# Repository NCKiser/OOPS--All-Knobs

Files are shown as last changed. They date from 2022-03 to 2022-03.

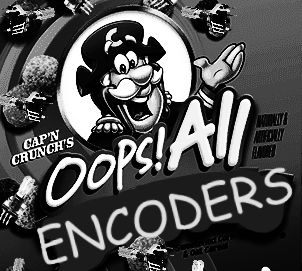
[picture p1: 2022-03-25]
imageedit_3_2700160076.png

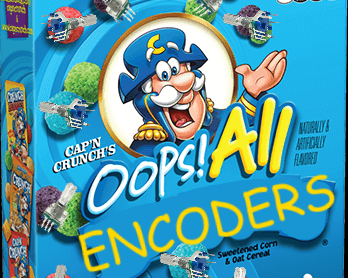
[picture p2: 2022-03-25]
PCBart.png

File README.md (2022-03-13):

# OOPS! All Encoders
A 19mm (Planck) spaced 4x12 PCB that has the option for an encoder in every switch position.
Runs on an rp2040. Should fit in most Planck cases low-, mid-, or high-profile.
There is currently no license for this work. Do not distribute or monetize without approval from Noah Kiser.

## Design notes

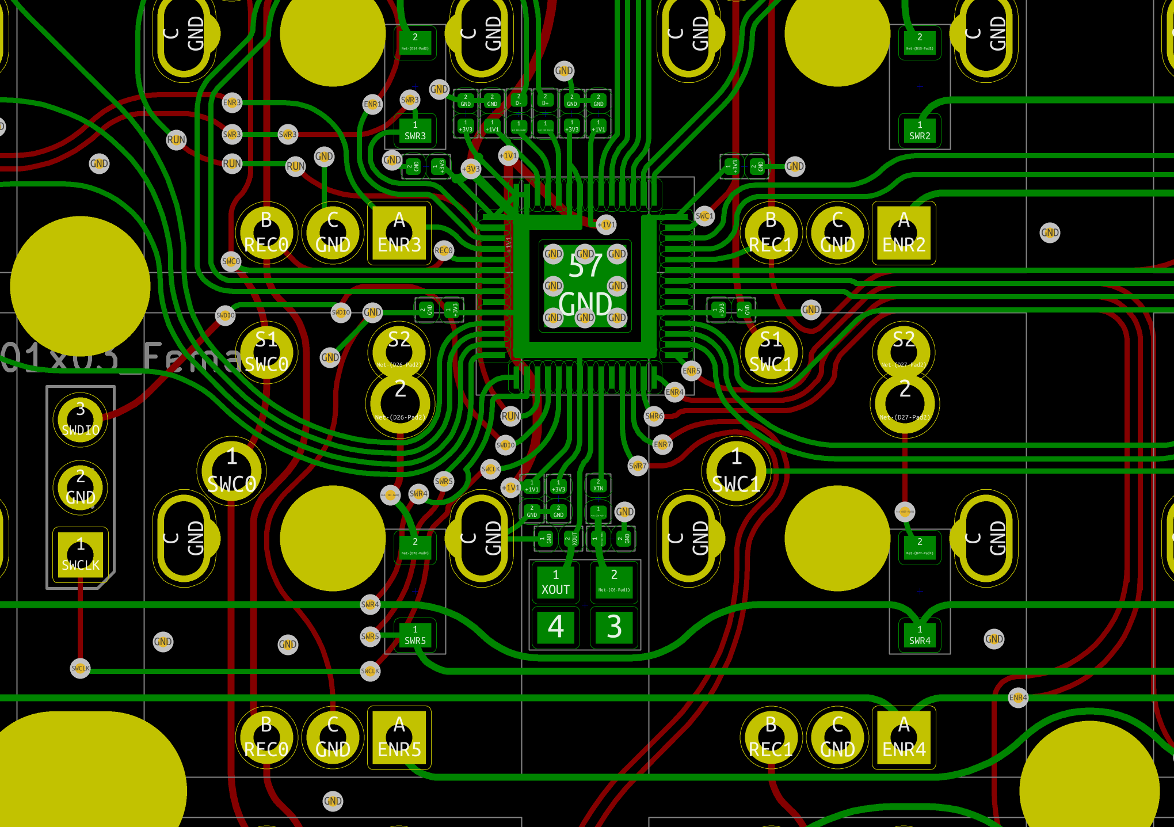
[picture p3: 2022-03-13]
Controller.png

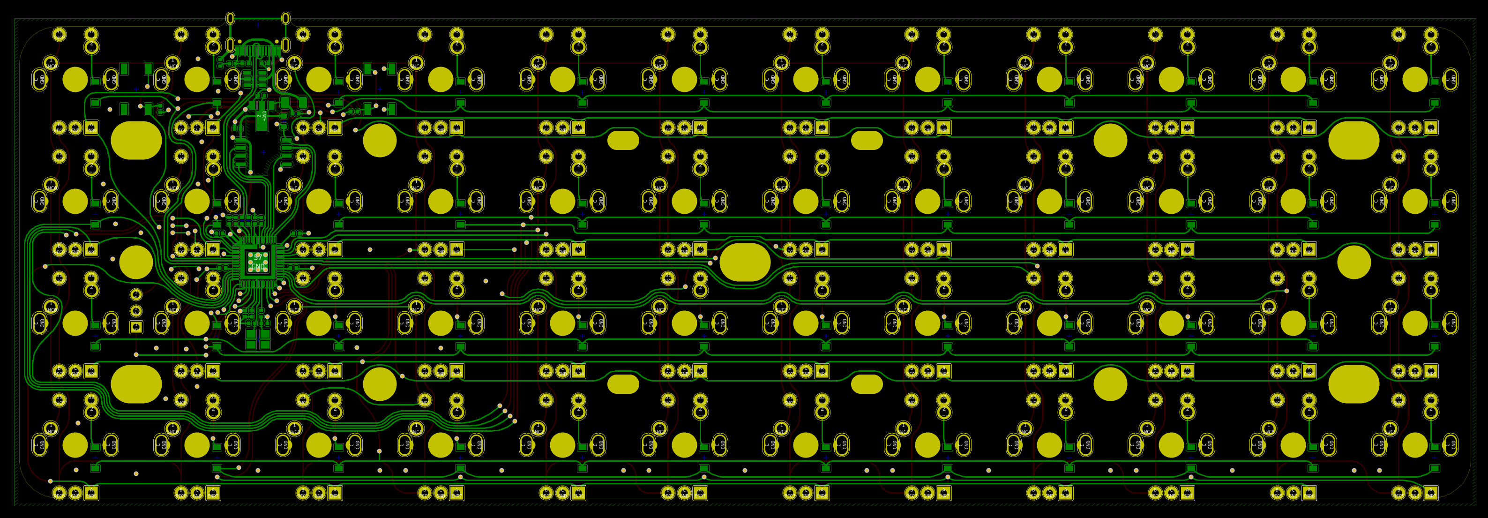
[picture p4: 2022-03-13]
PCB_Back.png

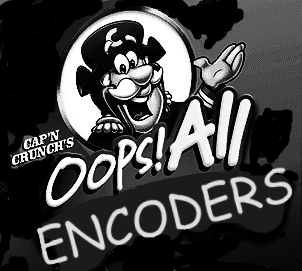
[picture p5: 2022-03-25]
imageedit_3_7217835309.png

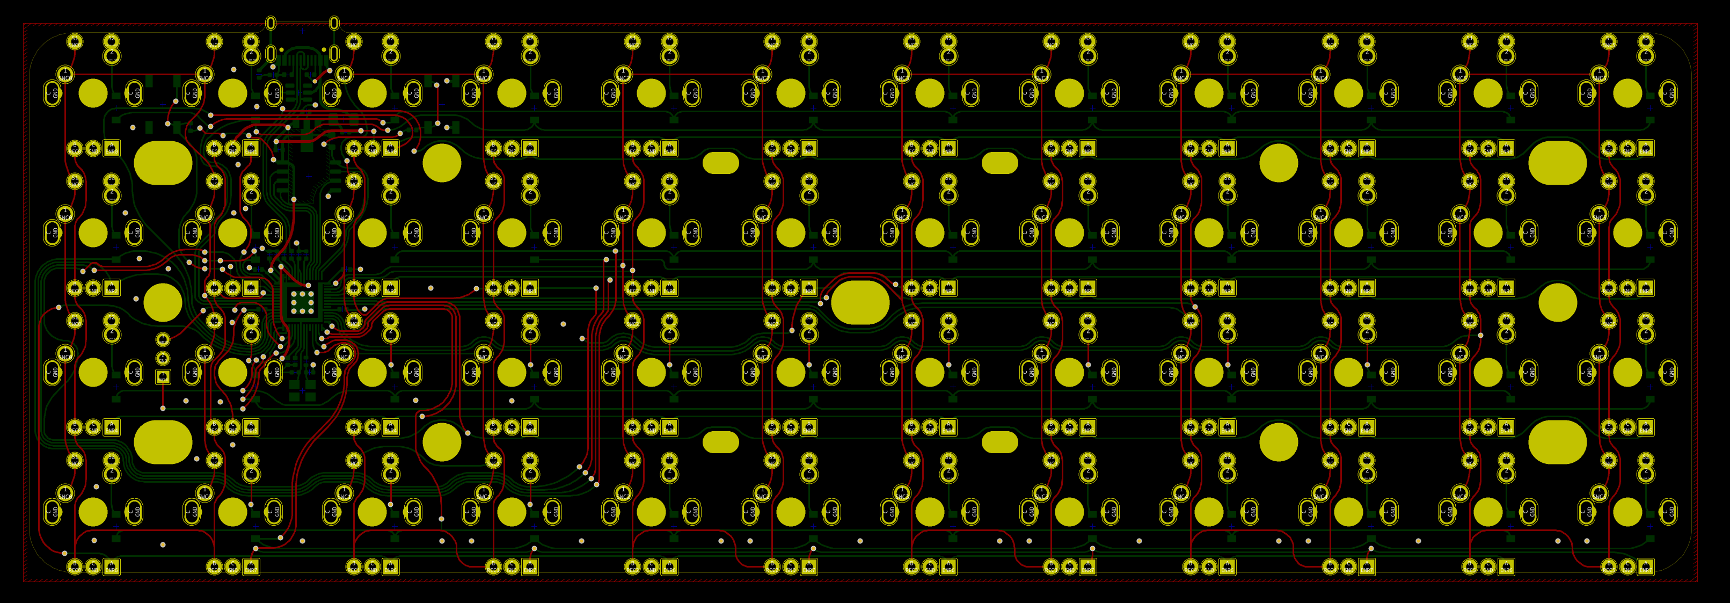
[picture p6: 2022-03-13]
PCB_Front.png

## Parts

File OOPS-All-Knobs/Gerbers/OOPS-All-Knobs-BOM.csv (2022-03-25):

Comment | Designator | Footprint | LCSC Part Number | Quantity
D_Small | D44,D9,D28,D4,D1,D23,D45,D43,D38,D16,D11,D26,D13,D39,D5,D19,D22,D36,D27,D21,D14,D37,D30,D35,D10,D12,D18,D34,D3,D48,D31,D42,D32,D25,D24,D41,D40,D8,D47,D33,D20,D29,D2,D15,D17,D6,D7,D46 | D_SOD-123 | C81598 | 48
100n | C10,C14,C4,C8,C12,C11,C13,C9,C7 | C_0402_1005Metric | C307331 | 9
1M | R3 | R_0402_1005Metric | C26083 | 1
1k | R8,R5 | R_0402_1005Metric | C11702 | 2
30p | C6,C5 | C_0402_1005Metric | C1570 | 2
XC6206-3.3_SOT23 | U1 | SOT-23 | C5446 | 1
SW_SPST | SW1,SW2 | SW_SPST_TL3342 | C318884 | 2
500mA | F1 | Fuse_1206_3216Metric | C70076 | 1
12MHz | Y1 | Crystal_SMD_3225-4Pin_3.2x2.5mm | C9002 | 1
22 | R6,R7 | R_0402_1005Metric | C25092 | 2
W25Q128JVS | U2 | SOIC-8_5.23x5.23mm_P1.27mm | C97521 | 1
USB_C_Receptacle_USB2.0 | J1 | USB_C_Receptacle_HRO_TYPE-C-31-M-12 | C165948 | 1
5.1k | R2,R9,R1 | R_0402_1005Metric | C25905 | 3
10u | C1,C2,C15 | C_0402_1005Metric | C15525 | 3
1u | C18,C17 | C_0402_1005Metric | C52923 | 2
SRV05-4 | U4 | SOT-23-6-routable | C85364 | 1
-10k | R4 | R_0603_1608Metric |  | 1
RP2040TR7 | U3 | QFN40P700X700X90-57N | C2040 | 1
4.7n | C3 | C_0402_1005Metric | C1538 | 1

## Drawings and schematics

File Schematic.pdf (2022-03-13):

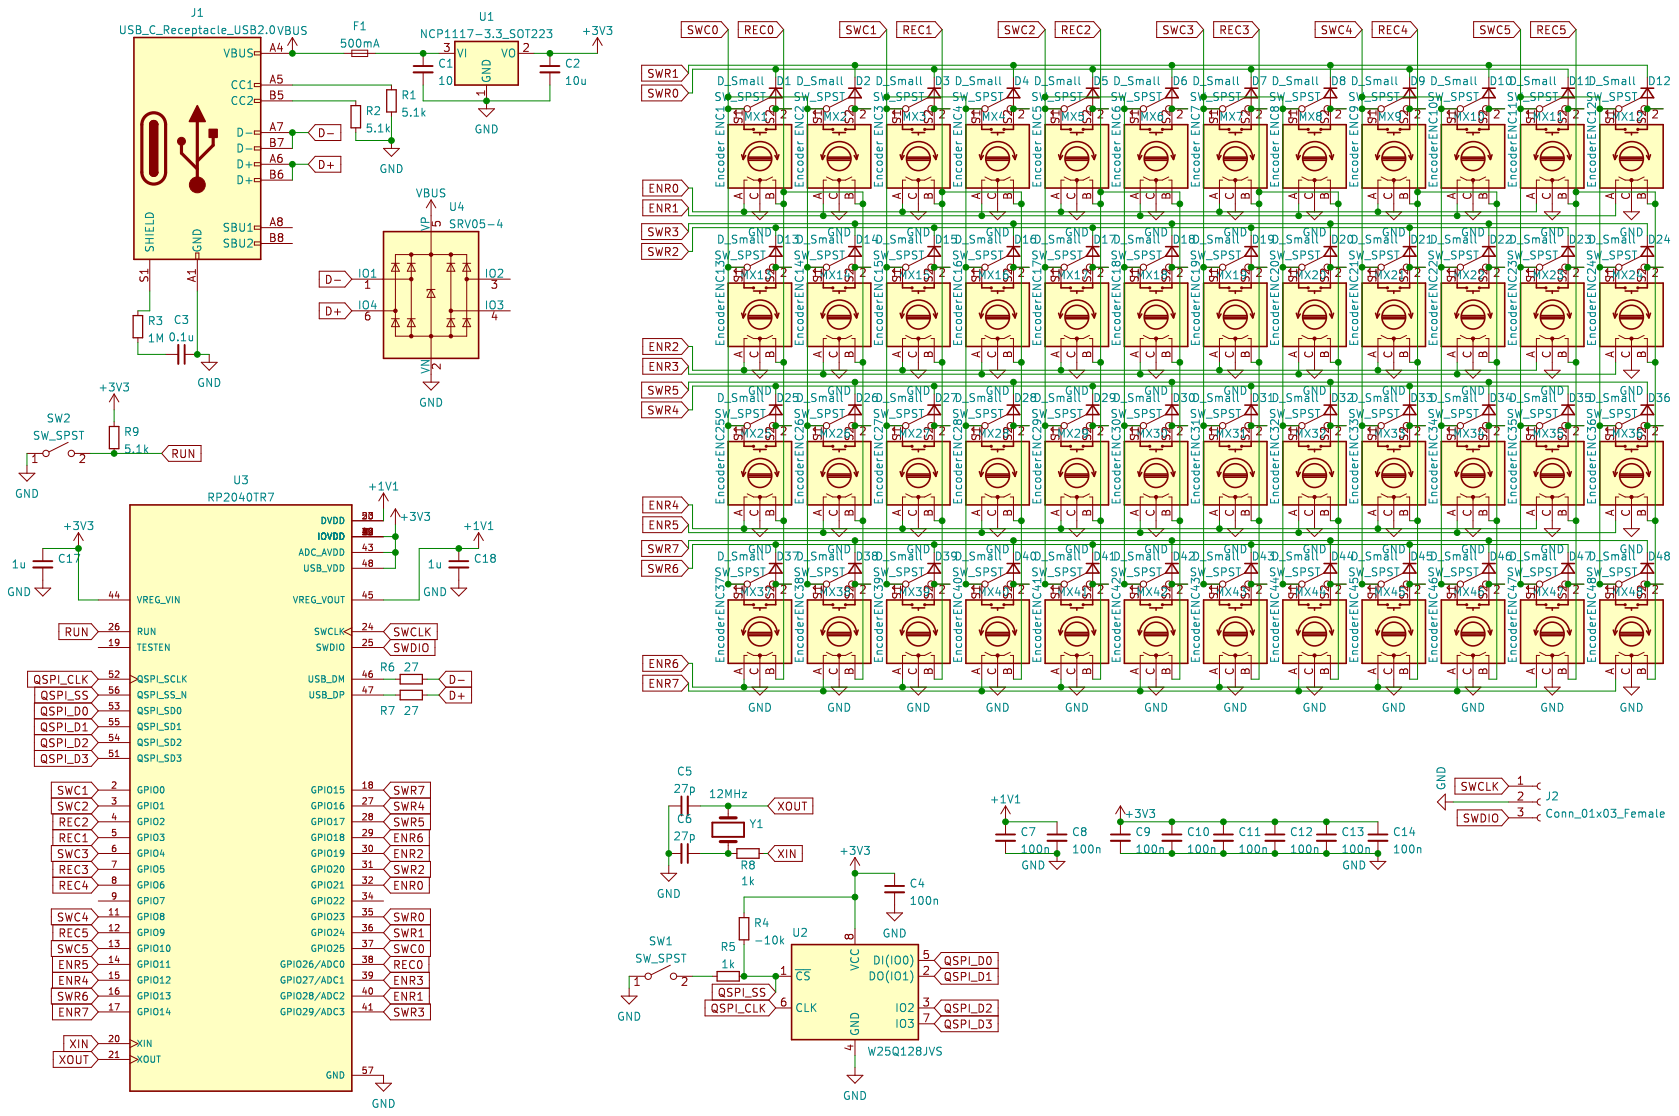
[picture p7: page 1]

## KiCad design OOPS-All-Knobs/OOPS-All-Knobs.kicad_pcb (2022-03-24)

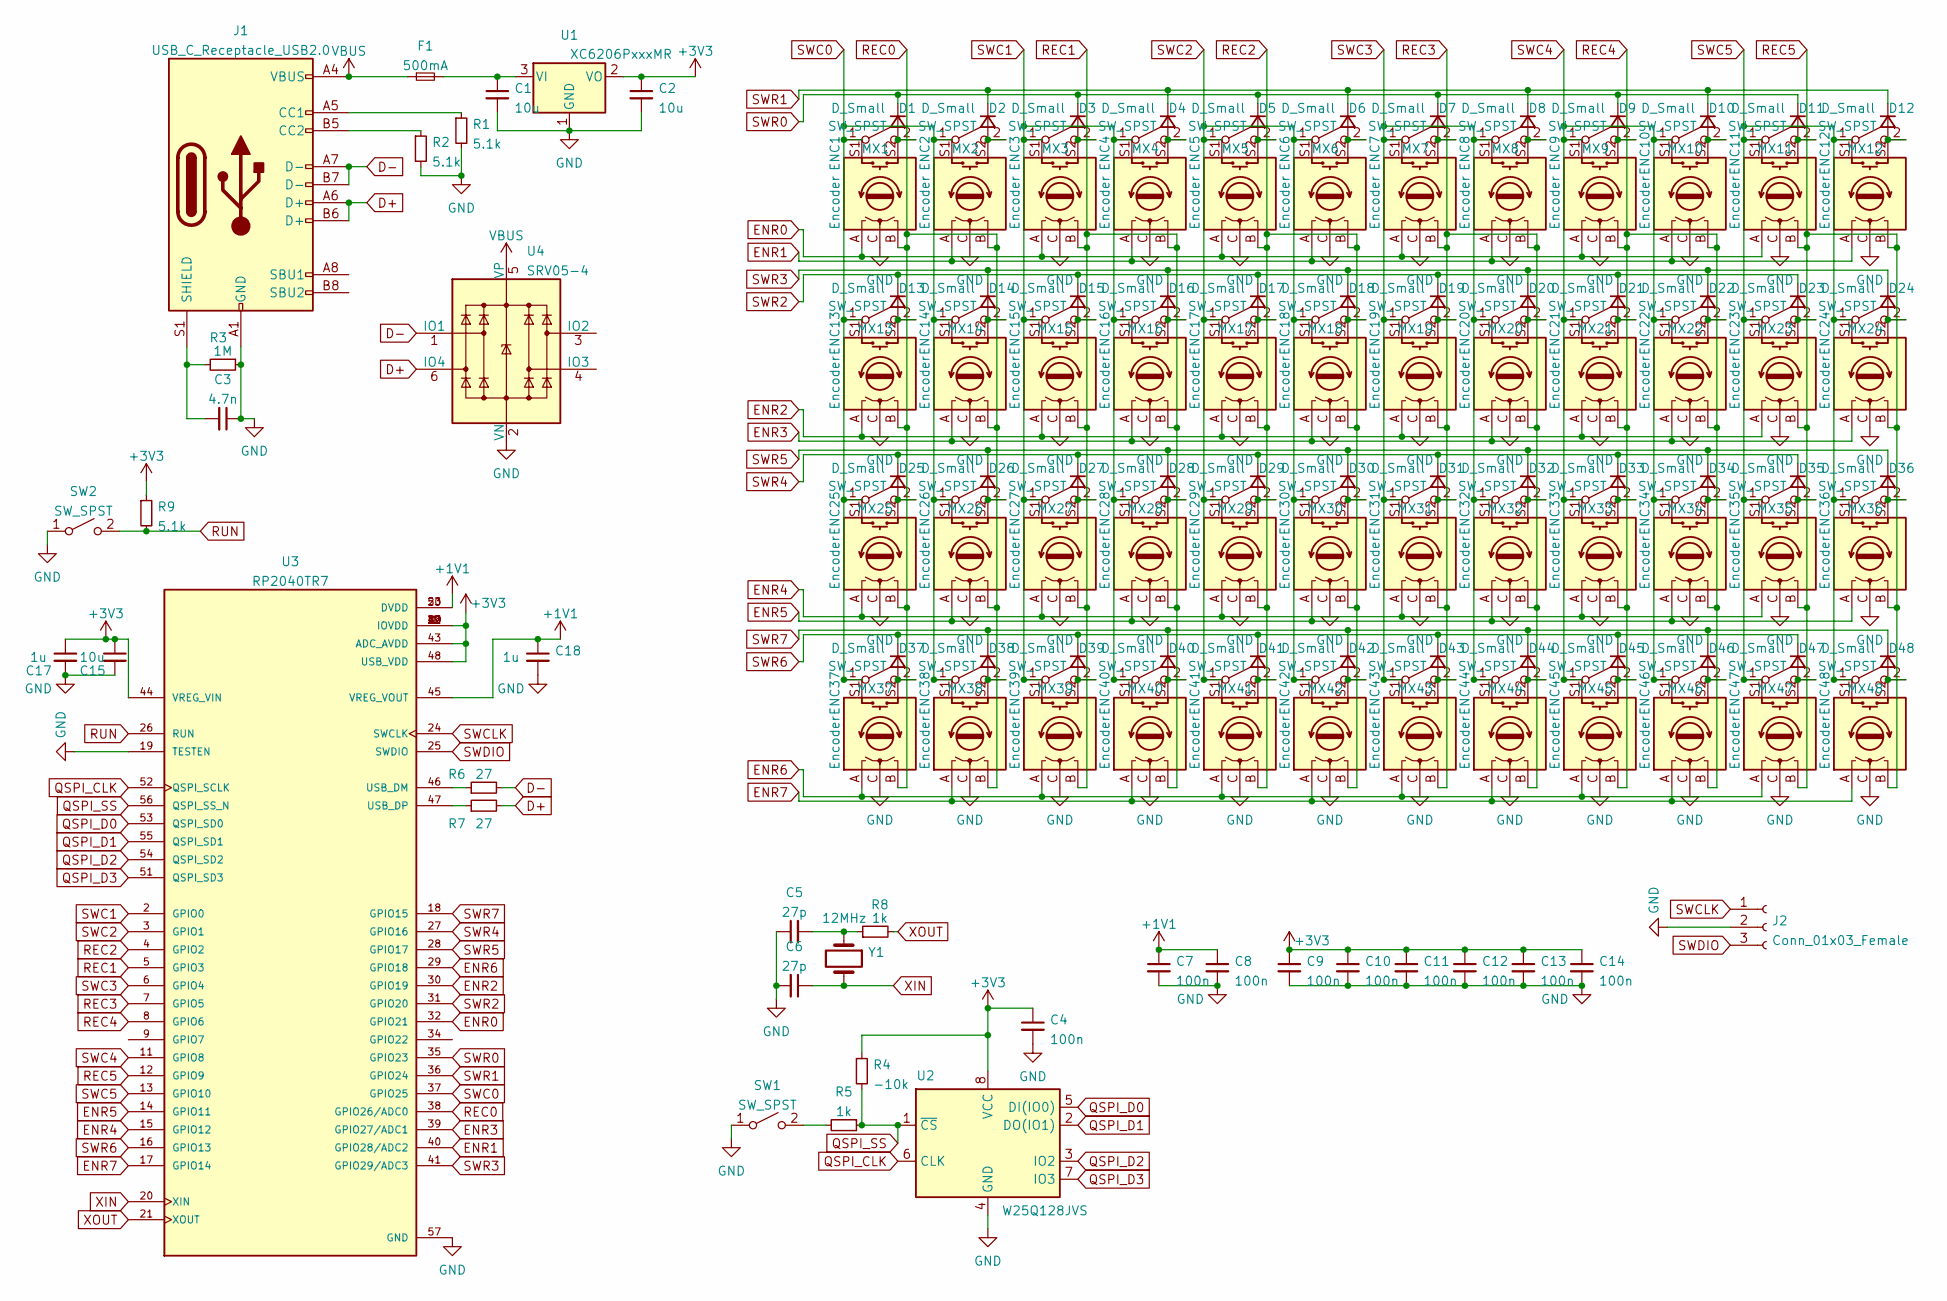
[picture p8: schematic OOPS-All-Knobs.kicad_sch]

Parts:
C1, C2, C15: 10u; C_0402_1005Metric
C3: 4.7n; C_0402_1005Metric
C4, C7, C8, C9, C10, C11, C12, C13, C14: 100n; C_0402_1005Metric
C5, C6: 27p; C_0402_1005Metric
C17, C18: 1u; C_0402_1005Metric
D1, D2, D3, D4, D5, D6, D7, D8, D9, D10, D11, D12, D13, D14, D15, D16, D17, D18, D19, D20, D21, D22, D23, D24, D25, D26, D27, D28, D29, D30, D31, D32, D33, D34, D35, D36, D37, D38, D39, D40, D41, D42, D43, D44, D45, D46, D47, D48: D_Small; D_SOD-123
ENC1, ENC2, ENC3, ENC4, ENC5, ENC6, ENC7, ENC8, ENC9, ENC10, ENC11, ENC12, ENC13, ENC14, ENC15, ENC16, ENC17, ENC18, ENC19, ENC20, ENC21, ENC22, ENC23, ENC24, ENC25, ENC26, ENC27, ENC28, ENC29, ENC30, ENC31, ENC32, ENC33, ENC34, ENC35, ENC36, ENC37, ENC38, ENC39, ENC40, ENC41, ENC42, ENC43, ENC44, ENC45, ENC46, ENC47, ENC48: Encoder; RotaryEncoder_Alps_EC11E-Switch_Vertical_H20mm
F1: 500mA; Fuse_1206_3216Metric
J1: USB_C_Receptacle_USB2.0; USB_C_Receptacle_HRO_TYPE-C-31-M-12
J2: Conn_01x03_Female; PinHeader_1x03_P2.54mm_Vertical
MX1, MX2, MX3, MX4, MX5, MX6, MX7, MX8, MX9, MX10, MX11, MX12, MX13, MX14, MX15, MX16, MX17, MX18, MX19, MX20, MX21, MX22, MX23, MX24, MX25, MX26, MX27, MX28, MX29, MX30, MX31, MX32, MX33, MX34, MX35, MX36, MX37, MX38, MX39, MX40, MX41, MX42, MX43, MX44, MX45, MX46, MX47, MX48: SW_SPST; MXOnly-1U-NoLED
R1, R2, R9: 5.1k; R_0402_1005Metric
R3: 1M; R_0402_1005Metric
R4: -10k; R_0603_1608Metric
R5, R8: 1k; R_0402_1005Metric
R6, R7: 27; R_0402_1005Metric
SW1, SW2: SW_SPST; SW_SPST_TL3342
U1: XC6206PxxxMR; SOT-23
U2: W25Q128JVS; SOIC-8_5.23x5.23mm_P1.27mm
U3: RP2040TR7; QFN40P700X700X90-57N; PARTREV 1.7.1
U4: SRV05-4; SOT-23-6-routable
Y1: 12MHz; Crystal_SMD_3225-4Pin_3.2x2.5mm

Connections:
+1V1: C7.1, C8.1, C18.1, U3.23 (DVDD), U3.45 (VREG_VOUT), U3.50 (DVDD)
+3V3: C2.1, C4.1, C9.1, C10.1, C11.1, C12.1, C13.1, C14.1, C15.1, C17.1, R4.1, R9.1, U1.2 (VO), U2.8 (VCC), U3.1 (IOVDD), U3.10 (IOVDD), U3.22 (IOVDD), U3.33 (IOVDD), U3.42 (IOVDD), U3.43 (ADC_AVDD), U3.44 (VREG_VIN), U3.48 (USB_VDD), U3.49 (IOVDD)
D+: J1.A6 (D+), J1.B6 (D+), R7.2, U4.6 (IO4)
D-: J1.A7 (D-), J1.B7 (D-), R6.2, U4.1 (IO1)
ENR0: ENC1.A, ENC3.A, ENC5.A, ENC7.A, ENC9.A, ENC11.A, U3.32 (GPIO21)
ENR1: ENC2.A, ENC4.A, ENC6.A, ENC8.A, ENC10.A, ENC12.A, U3.40 (GPIO28/ADC2)
ENR2: ENC13.A, ENC15.A, ENC17.A, ENC19.A, ENC21.A, ENC23.A, U3.30 (GPIO19)
ENR3: ENC14.A, ENC16.A, ENC18.A, ENC20.A, ENC22.A, ENC24.A, U3.39 (GPIO27/ADC1)
ENR4: ENC25.A, ENC27.A, ENC29.A, ENC31.A, ENC33.A, ENC35.A, U3.15 (GPIO12)
ENR5: ENC26.A, ENC28.A, ENC30.A, ENC32.A, ENC34.A, ENC36.A, U3.14 (GPIO11)
ENR6: ENC37.A, ENC39.A, ENC41.A, ENC43.A, ENC45.A, ENC47.A, U3.29 (GPIO18)
ENR7: ENC38.A, ENC40.A, ENC42.A, ENC44.A, ENC46.A, ENC48.A, U3.17 (GPIO14)
GND: C1.2, C2.2, C3.1, C4.2, C5.1, C6.2, C7.2, C8.2, C9.2, C10.2, C11.2, C12.2, C13.2, C14.2, C15.2, C17.2, C18.2, ENC1.C, ENC2.C, ENC3.C, ENC4.C, ENC5.C, ENC6.C, ENC7.C, ENC8.C, ENC9.C, ENC10.C, ENC11.C, ENC12.C, ENC13.C, ENC14.C, ENC15.C, ENC16.C, ENC17.C, ENC18.C, ENC19.C, ENC20.C, ENC21.C, ENC22.C, ENC23.C, ENC24.C, ENC25.C, ENC26.C, ENC27.C, ENC28.C, ENC29.C, ENC30.C, ENC31.C, ENC32.C, ENC33.C, ENC34.C, ENC35.C, ENC36.C, ENC37.C, ENC38.C, ENC39.C, ENC40.C, ENC41.C, ENC42.C, ENC43.C, ENC44.C, ENC45.C, ENC46.C, ENC47.C, ENC48.C, J1.A1 (GND), J1.A12 (GND), J1.B1 (GND), J1.B12 (GND), J2.2, R1.2, R2.2, R3.1, SW1.1 (A), SW2.1 (A), U1.1 (GND), U2.4 (GND), U3.19 (TESTEN), U3.57 (GND), U4.2 (VN)
unnamed: C1.1, F1.2, U1.3 (VI)
unnamed: C3.2, J1.S1 (SHIELD), R3.2
unnamed: C5.2, R8.1, Y1.1
unnamed: D1.2 (A), ENC1.S2, MX1.2 (B)
unnamed: D2.2 (A), ENC2.S2, MX2.2 (B)
unnamed: D3.2 (A), ENC3.S2, MX3.2 (B)
unnamed: D4.2 (A), ENC4.S2, MX4.2 (B)
unnamed: D5.2 (A), ENC5.S2, MX5.2 (B)
unnamed: D6.2 (A), ENC6.S2, MX6.2 (B)
unnamed: D7.2 (A), ENC7.S2, MX7.2 (B)
unnamed: D8.2 (A), ENC8.S2, MX8.2 (B)
unnamed: D9.2 (A), ENC9.S2, MX9.2 (B)
unnamed: D10.2 (A), ENC10.S2, MX10.2 (B)
unnamed: D11.2 (A), ENC11.S2, MX11.2 (B)
unnamed: D12.2 (A), ENC12.S2, MX12.2 (B)
unnamed: D13.2 (A), ENC13.S2, MX13.2 (B)
unnamed: D14.2 (A), ENC14.S2, MX14.2 (B)
unnamed: D15.2 (A), ENC15.S2, MX15.2 (B)
unnamed: D16.2 (A), ENC16.S2, MX16.2 (B)
unnamed: D17.2 (A), ENC17.S2, MX17.2 (B)
unnamed: D18.2 (A), ENC18.S2, MX18.2 (B)
unnamed: D19.2 (A), ENC19.S2, MX19.2 (B)
unnamed: D20.2 (A), ENC20.S2, MX20.2 (B)
unnamed: D21.2 (A), ENC21.S2, MX21.2 (B)
unnamed: D22.2 (A), ENC22.S2, MX22.2 (B)
unnamed: D23.2 (A), ENC23.S2, MX23.2 (B)
unnamed: D24.2 (A), ENC24.S2, MX24.2 (B)
unnamed: D25.2 (A), ENC25.S2, MX25.2 (B)
unnamed: D26.2 (A), ENC26.S2, MX26.2 (B)
unnamed: D27.2 (A), ENC27.S2, MX27.2 (B)
unnamed: D28.2 (A), ENC28.S2, MX28.2 (B)
unnamed: D29.2 (A), ENC29.S2, MX29.2 (B)
unnamed: D30.2 (A), ENC30.S2, MX30.2 (B)
unnamed: D31.2 (A), ENC31.S2, MX31.2 (B)
unnamed: D32.2 (A), ENC32.S2, MX32.2 (B)
unnamed: D33.2 (A), ENC33.S2, MX33.2 (B)
unnamed: D34.2 (A), ENC34.S2, MX34.2 (B)
unnamed: D35.2 (A), ENC35.S2, MX35.2 (B)
unnamed: D36.2 (A), ENC36.S2, MX36.2 (B)
unnamed: D37.2 (A), ENC37.S2, MX37.2 (B)
unnamed: D38.2 (A), ENC38.S2, MX38.2 (B)
unnamed: D39.2 (A), ENC39.S2, MX39.2 (B)
unnamed: D40.2 (A), ENC40.S2, MX40.2 (B)
unnamed: D41.2 (A), ENC41.S2, MX41.2 (B)
unnamed: D42.2 (A), ENC42.S2, MX42.2 (B)
unnamed: D43.2 (A), ENC43.S2, MX43.2 (B)
unnamed: D44.2 (A), ENC44.S2, MX44.2 (B)
unnamed: D45.2 (A), ENC45.S2, MX45.2 (B)
unnamed: D46.2 (A), ENC46.S2, MX46.2 (B)
unnamed: D47.2 (A), ENC47.S2, MX47.2 (B)
unnamed: D48.2 (A), ENC48.S2, MX48.2 (B)
unnamed: J1.A5 (CC1), R1.1
unnamed: J1.B5 (CC2), R2.1
unnamed: R5.2, SW1.2 (B)
unnamed: R6.1, U3.46 (USB_DM)
unnamed: R7.1, U3.47 (USB_DP)
QSPI_CLK: U2.6 (CLK), U3.52 (QSPI_SCLK)
QSPI_D0: U2.5 (DI(IO0)), U3.53 (QSPI_SD0)
QSPI_D1: U2.2 (DO(IO1)), U3.55 (QSPI_SD1)
QSPI_D2: U2.3 (IO2), U3.54 (QSPI_SD2)
QSPI_D3: U2.7 (IO3), U3.51 (QSPI_SD3)
QSPI_SS: R4.2, R5.1, U2.1 (~CS), U3.56 (QSPI_SS_N)
REC0: ENC1.B, ENC2.B, ENC13.B, ENC14.B, ENC25.B, ENC26.B, ENC37.B, ENC38.B, U3.38 (GPIO26/ADC0)
REC1: ENC3.B, ENC4.B, ENC15.B, ENC16.B, ENC27.B, ENC28.B, ENC39.B, ENC40.B, U3.5 (GPIO3)
REC2: ENC5.B, ENC6.B, ENC17.B, ENC18.B, ENC29.B, ENC30.B, ENC41.B, ENC42.B, U3.4 (GPIO2)
REC3: ENC7.B, ENC8.B, ENC19.B, ENC20.B, ENC31.B, ENC32.B, ENC43.B, ENC44.B, U3.7 (GPIO5)
REC4: ENC9.B, ENC10.B, ENC21.B, ENC22.B, ENC33.B, ENC34.B, ENC45.B, ENC46.B, U3.8 (GPIO6)
REC5: ENC11.B, ENC12.B, ENC23.B, ENC24.B, ENC35.B, ENC36.B, ENC47.B, ENC48.B, U3.12 (GPIO9)
RUN: R9.2, SW2.2 (B), U3.26 (RUN)
SWC0: ENC1.S1, ENC2.S1, ENC13.S1, ENC14.S1, ENC25.S1, ENC26.S1, ENC37.S1, ENC38.S1, MX1.1 (A), MX2.1 (A), MX13.1 (A), MX14.1 (A), MX25.1 (A), MX26.1 (A), MX37.1 (A), MX38.1 (A), U3.37 (GPIO25)
SWC1: ENC3.S1, ENC4.S1, ENC15.S1, ENC16.S1, ENC27.S1, ENC28.S1, ENC39.S1, ENC40.S1, MX3.1 (A), MX4.1 (A), MX15.1 (A), MX16.1 (A), MX27.1 (A), MX28.1 (A), MX39.1 (A), MX40.1 (A), U3.2 (GPIO0)
SWC2: ENC5.S1, ENC6.S1, ENC17.S1, ENC18.S1, ENC29.S1, ENC30.S1, ENC41.S1, ENC42.S1, MX5.1 (A), MX6.1 (A), MX17.1 (A), MX18.1 (A), MX29.1 (A), MX30.1 (A), MX41.1 (A), MX42.1 (A), U3.3 (GPIO1)
SWC3: ENC7.S1, ENC8.S1, ENC19.S1, ENC20.S1, ENC31.S1, ENC32.S1, ENC43.S1, ENC44.S1, MX7.1 (A), MX8.1 (A), MX19.1 (A), MX20.1 (A), MX31.1 (A), MX32.1 (A), MX43.1 (A), MX44.1 (A), U3.6 (GPIO4)
SWC4: ENC9.S1, ENC10.S1, ENC21.S1, ENC22.S1, ENC33.S1, ENC34.S1, ENC45.S1, ENC46.S1, MX9.1 (A), MX10.1 (A), MX21.1 (A), MX22.1 (A), MX33.1 (A), MX34.1 (A), MX45.1 (A), MX46.1 (A), U3.11 (GPIO8)
SWC5: ENC11.S1, ENC12.S1, ENC23.S1, ENC24.S1, ENC35.S1, ENC36.S1, ENC47.S1, ENC48.S1, MX11.1 (A), MX12.1 (A), MX23.1 (A), MX24.1 (A), MX35.1 (A), MX36.1 (A), MX47.1 (A), MX48.1 (A), U3.13 (GPIO10)
SWCLK: J2.1, U3.24 (SWCLK)
SWDIO: J2.3, U3.25 (SWDIO)
SWR0: D1.1 (K), D3.1 (K), D5.1 (K), D7.1 (K), D9.1 (K), D11.1 (K), U3.35 (GPIO23)
SWR1: D2.1 (K), D4.1 (K), D6.1 (K), D8.1 (K), D10.1 (K), D12.1 (K), U3.36 (GPIO24)
SWR2: D13.1 (K), D15.1 (K), D17.1 (K), D19.1 (K), D21.1 (K), D23.1 (K), U3.31 (GPIO20)
SWR3: D14.1 (K), D16.1 (K), D18.1 (K), D20.1 (K), D22.1 (K), D24.1 (K), U3.41 (GPIO29/ADC3)
SWR4: D25.1 (K), D27.1 (K), D29.1 (K), D31.1 (K), D33.1 (K), D35.1 (K), U3.27 (GPIO16)
SWR5: D26.1 (K), D28.1 (K), D30.1 (K), D32.1 (K), D34.1 (K), D36.1 (K), U3.28 (GPIO17)
SWR6: D37.1 (K), D39.1 (K), D41.1 (K), D43.1 (K), D45.1 (K), D47.1 (K), U3.16 (GPIO13)
SWR7: D38.1 (K), D40.1 (K), D42.1 (K), D44.1 (K), D46.1 (K), D48.1 (K), U3.18 (GPIO15)
VBUS: F1.1, J1.A4 (VBUS), J1.A9 (VBUS), J1.B4 (VBUS), J1.B9 (VBUS), U4.5 (VP)
XIN: C6.1, U3.20 (XIN), Y1.2
XOUT: R8.2, U3.21 (XOUT)

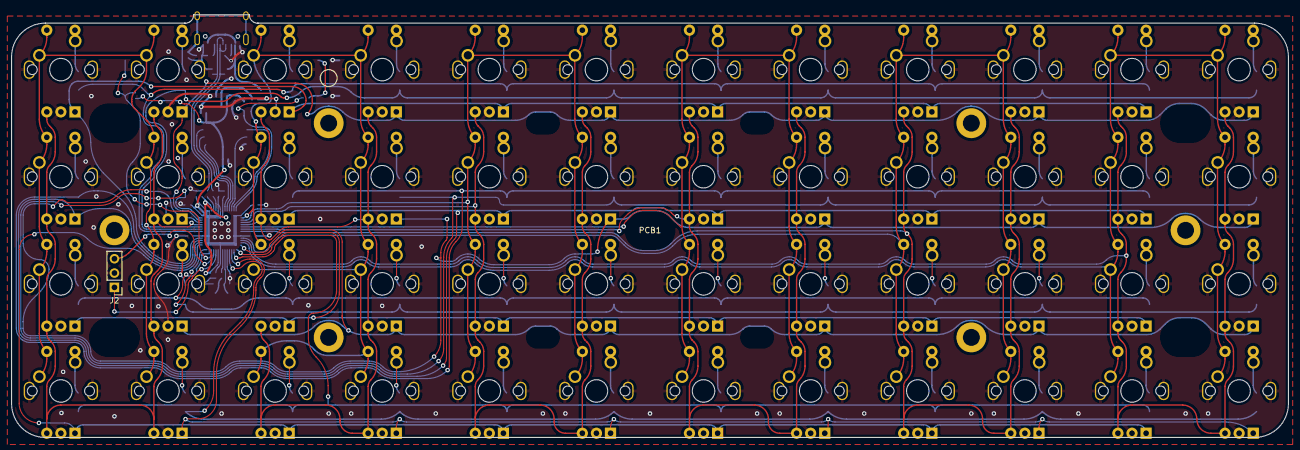
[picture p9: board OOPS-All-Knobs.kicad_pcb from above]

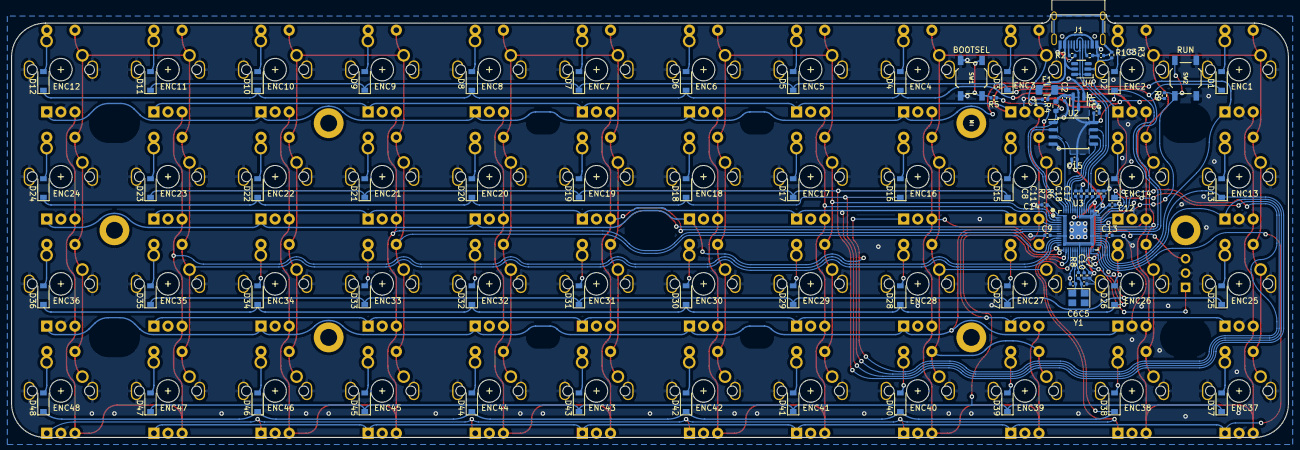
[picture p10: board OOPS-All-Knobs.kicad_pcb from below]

Board: 2 copper layers, 226.5 x 75.0 mm, 181 parts (131 on the bottom side), 101 nets.

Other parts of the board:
PCB1: planck-pcb-module

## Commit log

2022-03-09 initial matrix
    [OOPS-All-Knobs.kicad_pcb, OOPS-All-Knobs.kicad_sch]
2022-03-09 Added ground
    [OOPS-All-Knobs.kicad_sch]
2022-03-09 Added Planck footprint
    [OOPS-All-Knobs.kicad_pcb]
2022-03-10 Placed and routed controller
    [OOPS-All-Knobs.kicad_pcb, OOPS-All-Knobs.kicad_sch]
2022-03-12 Some progress on routing matrices
    [OOPS-All-Knobs.kicad_pcb, OOPS-All-Knobs.kicad_sch]
2022-03-12 routed controller, just a few connections left
    [OOPS-All-Knobs.kicad_pcb, OOPS-All-Knobs.kicad_sch]
2022-03-13 More ground stitching, pics and schematic
    [OOPS-All-Knobs.kicad_pcb]
2022-03-13 Implemented proposed fixes for testgen, shielding, and xtal
    [OOPS-All-Knobs.kicad_pcb, OOPS-All-Knobs.kicad_sch]
2022-03-13 a few more improvements
    [OOPS-All-Knobs.kicad_pcb, OOPS-All-Knobs.kicad_sch]
2022-03-24 Gerbers ready for manu
    [OOPS-All-Knobs-BOM.csv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]
2022-03-24 Everything but the crystal
    [OOPS-All-Knobs-BOM.csv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]
2022-03-25 Ready for Manu!
    [OOPS-All-Knobs-BOM.csv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]
2022-04-13 change encoder footprints
